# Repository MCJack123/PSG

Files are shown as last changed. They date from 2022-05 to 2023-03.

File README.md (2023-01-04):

# JackMacWindows's Programmable Sound Generator
This repo contains the source code for my programmable sound generation board. [Read the article for more info.](https://mcjack123.github.io/PSG/)

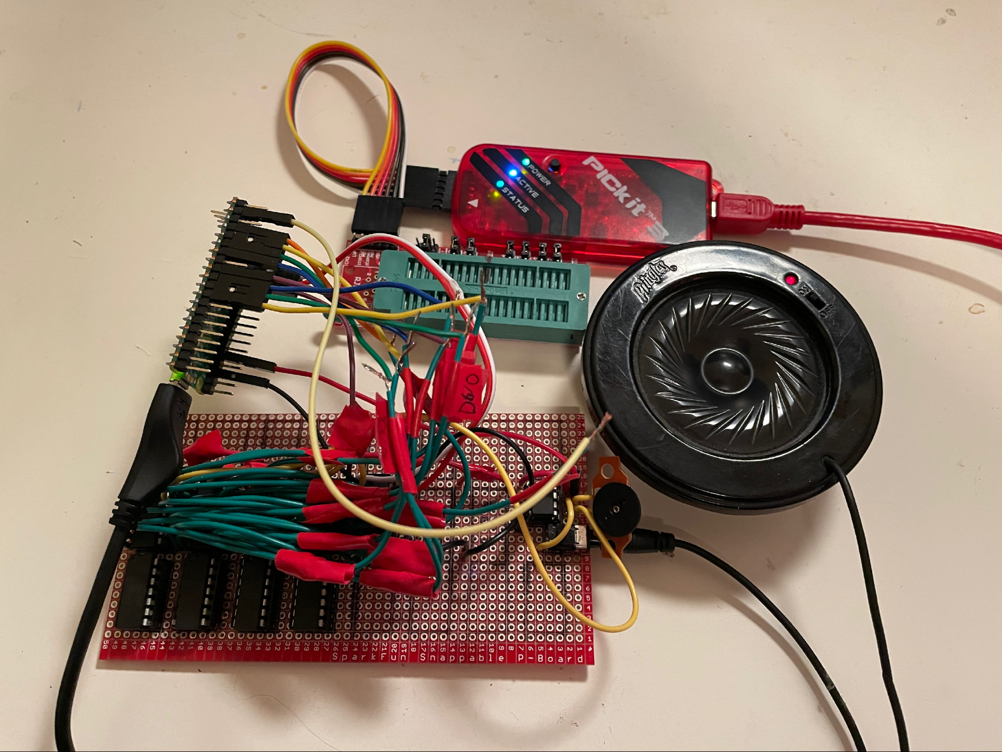
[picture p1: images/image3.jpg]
PSG image

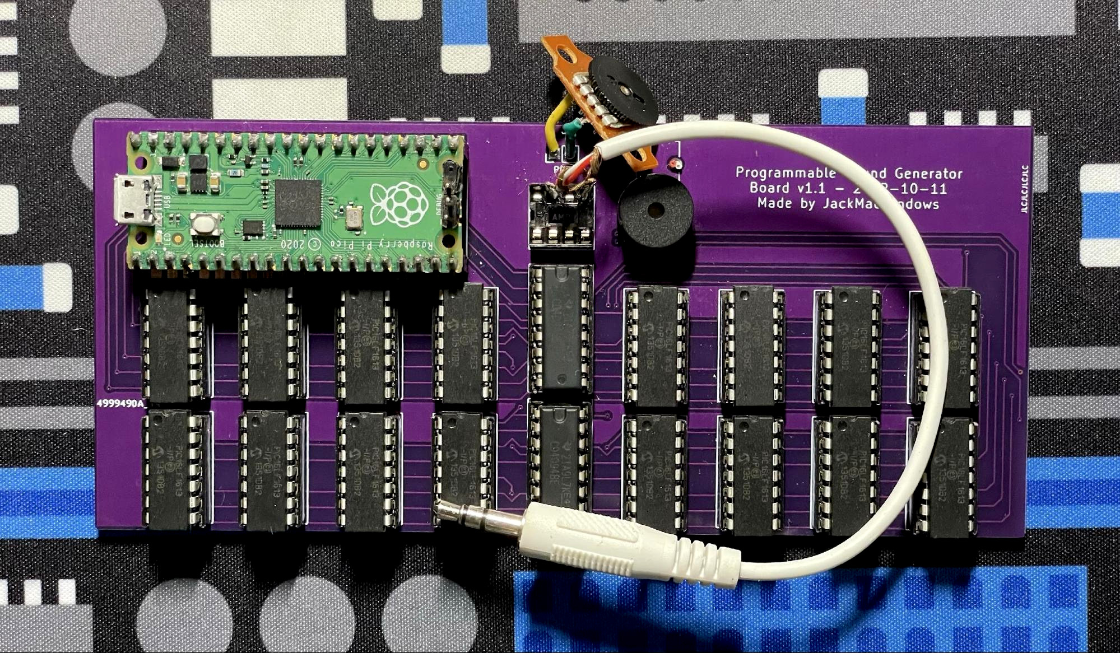
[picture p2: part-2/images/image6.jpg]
PSG image 2


## Contents
* `PSG-PCB` is a KiCad PCB layout for the complete 16-channel board.
* `PSG.X` contains an MPLAB X project with the wave generator code for the microcontrollers.
* `pico-sound-driver` contains a Raspberry Pi Pico project for managing the MCUs with a USB MIDI interface.
* `sound-midi.cpp` is a CraftOS-PC plugin for connecting to the board using the `sound` plugin interface.
* `programmer.cpp` is a program to quickly flash UF2, HEX, or BIN (concatenated HEX + UF2) firmware files to the PIC chips and the Pico. The current production firmware is available in `firmware.bin`.
* [`instrument-designer.html`](https://mcjack123.github.io/PSG/instrument-designer.html) is a small HTML+JS app to quickly design and upload instrument patches to the board.

## Documentation

### Mono/Poly Mode
The board has two different modes available. These modes are controlled by the standard CCs 126 and 127.

In mono mode, each channel can play one frequency and has its own global program and volume settings. This has a 1:1 correlation with each chip - one MIDI channel controls its corresponding chip number. Instruments are not available in this mode - instead, the program number (from 0-7, looping after) controls the wave type directly, as if the instrument bank was just initialized.

In poly mode, chips are allocated as needed for each note to play. Programs are assigned to each channel, and instruments are available.

### Direct Parameter Control
To support being able to directly control the parameters of each chip, some CCs are added to control the frequency instead of requiring note+pitch bend messages. See below for more information on those. In addition, when in mono mode, the standard volume and program change settings will directly affect the chips.

### Stereo Support
Firmware version 1.2.0 adds support for stereo output on board revisions that support it (v1.2.0 or later). There are three modes available: center (default), split stereo, and full stereo. In split stereo mode, all 16 voices are available, but the first eight will go straight to the left side, and the second eight will go to the right side. This is most effective when in mono note mode. Full stereo reduces the number of available voices to 8, but plays notes with chips on both sides, making them audible on both sides, as well as enabling panning using the CC & envelope.

### Instruments
Instruments allow attaching envelopes to waves for continuous changes to certain parameters. Four envelopes are available for controlling volume, panning, frequency adjustment, and duty cycle (square waves only). Instruments replace basic wave type controls in poly mode, and all 128 programs in MIDI have instruments attached.

Envelopes are based on the XM module format's envelope design. Each envelope has a maximum of 12 points available, each storing 16-bit pairs of X/Y coordinates. The X axis indicates the time of the point, in hundredths of a second. The Y axis stores the MIDI value of the control for everything except frequency. The frequency envelope's Y axis is the number of 16ths of a semitone to offset the note by, with a value of `0x8000` being centered at ±0.

Each envelope also has the ability to loop between certain points. There are three modes: one shot, which plays the envelope straight and ends at the last point, regardless of note off; sustain, which holds the envelope position at the *sustain point* until the note is released; and loop, which jumps the position in the envelope back to the loop start point when it reaches the loop end point. (Sustain mode functions like loop mode as if the start and end point were the same.)

By default, the instrument list is filled with basic instruments with no envelopes. The wave types cycle in the same order as mono mode, but program numbers divisible by 8 hold square waves with increasing default duty levels (for example, program 8 is a 1/16 duty square wave, program 32 is a 1/4 duty square wave, etc.). Program 0 is also set to a 1/2 duty square wave, as a duty of 0 is invalid.

### CC List
This table lists all available CCs.

| CC  | Description |
|-----|---|
| 1 | Square wave duty cycle |
| 7 | Volume |
| 10  | Pan (full stereo mode only) |
| 24  | Frequency (MSB) |
| 56  | Frequency (LSB) |
| 86  | Stereo mode: `0x40` -> stereo enable bit, `0x20` -> dual channel bit |
| 123 | All notes off |
| 126 | Mono mode |
| 127 | Poly mode |

### Wave Types
| Code | Wave |
|---|---|
| 0 | None, or square |
| 1 | Sine |
| 2 | Triangle |
| 3 | Saw (ascending) |
| 4 | Saw (descending) |
| 5 | Square |
| 6 | Noise  |
| 7 | Undefined |

### SysEx List
PSG accepts SysEx commands with vendor ID `00 46 71`. Commands are followed by two bytes for the command number in little endian.

| Command | Data | Description |
|---|---|---|
| `00 00` | HEX file | Flash PIC firmware to all attached chips |
| `01 F7` | None | Enter UF2 bootloader mode |
| `02 00` | Patch number, instrument data | Upload instrument data to program slot |

#### Instrument data
Instruments are stored in a 212-byte binary block encoded with Base64. Point coordinates are in little endian.

| Offset | Size | Description |
|---|---|---|
| `0x00` | 2 | X coordinate of first point in volume envelope |
| `0x02` | 2 | Y coordinate of first point in volume envelope |
| `0x04` | 2/2  | X/Y coordinates of second point in volume envelope |
| `0x08` | 40 | ...10 more points |
| `0x30` | 1 | Number of points in volume envelope |
| `0x31` | 1 | Sustain point number in volume envelope (`0xFF` = no sustain) |
| `0x32` | 1 | Loop start point number in volume envelope (`0xFF` = no loop) |
| `0x33` | 1 | Loop end point number in volume envelope (`0xFF` = no loop) |
| `0x34` | 52 | Pan envelope |
| `0x68` | 52 | Frequency envelope |
| `0x9C` | 52 | Duty envelope |
| `0xD0` | 1 | Wave type |
| `0xD1` | 3 | Reserved, set to 0 |

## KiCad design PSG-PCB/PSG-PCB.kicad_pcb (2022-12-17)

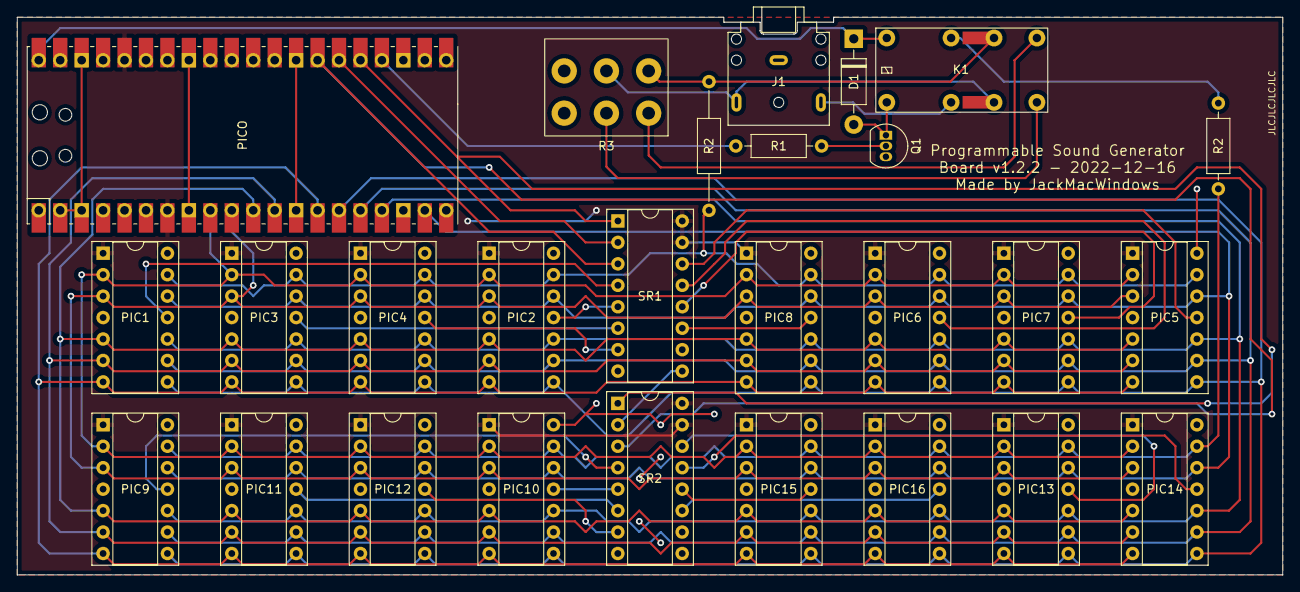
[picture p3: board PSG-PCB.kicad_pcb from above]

Board: 2 copper layers, 149.9 x 66.0 mm, 9 parts (0 on the bottom side), 12 nets.

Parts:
D1: D_DO-41_SOD81_P10.16mm_Horizontal
J1: Jack_3.5mm_CUI_SJ1-3523N_Horizontal
K1: Relay_DPDT_CIT_J104D
PICO: RPi_Pico_SMD_TH
Q1: TO-92_Inline
R1: 1K; R_Axial_DIN0207_L6.3mm_D2.5mm_P10.16mm_Horizontal
R2: 150K; R_Axial_DIN0207_L6.3mm_D2.5mm_P15.24mm_Horizontal
R2#2: 150K; R_Axial_DIN0207_L6.3mm_D2.5mm_P10.16mm_Horizontal
R3: Potentiometer_Bourns_PDB182-K_Horizontal

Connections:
5V: D1.1, K1.1, PICO.40
Audio_In_Amp: K1.5, R2.2, R3.3
Audio_In_R_Amp: K1.7, R3.6
Audio_In_R_Res: K1.3, R2#2.2
Audio_Out: J1.T, K1.6, R3.2
Audio_Out_R: K1.8, R3.5
Audio_Pin_R: J1.R, K1.4
Ground: J1.S, PICO.1, PICO.2, PICO.3, PICO.4, PICO.5, PICO.6, PICO.8, PICO.13, PICO.18, PICO.23, PICO.28, PICO.33, PICO.38, Q1.3, R3.1, R3.4
Relay_Sink: D1.2, K1.2, Q1.1
Stereo: PICO.24, R1.1
T_Base: Q1.2, R1.2
VDD: PICO.7, PICO.36

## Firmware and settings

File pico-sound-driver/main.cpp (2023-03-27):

/*
 * pico-sound-driver/main.cpp
 * PSG
 *
 * This file contains the firmware for the Raspberry Pi Pico. It handles parsing
 * MIDI events and converting them into commands for each channel, as well as
 * other miscellaneous functionality, such as fade out and PIC firmware updates.
 *
 * This code is licensed under the GPLv2 license.
 * Copyright (c) 2022-2023 JackMacWindows.
 */

#include <hardware/flash.h>
#include <hardware/gpio.h>
#include <hardware/timer.h>
#include <hardware/watchdog.h>
#include <pico/mutex.h>
#include <pico/multicore.h>
#include <pico/bootrom.h>
#include <tusb.h>
#include <math.h>
#include <stdio.h>

#define BOARD_VERSION_MAJOR 0
#define BOARD_VERSION_MINOR 1

#define MAX_CHANNELS 16
#define NUM_CHANNELS (dualChannel ? MAX_CHANNELS / 2 : MAX_CHANNELS)
#ifndef M_PI
#define M_PI 3.14159265358979323846
#endif

#define gpio_out(pin) gpio_init(pin); gpio_set_dir(pin, true)
#define gpio_in(pin) gpio_init(pin); gpio_set_dir(pin, false)
#define COMMAND_WAVE_TYPE 0x00
#define COMMAND_VOLUME    0x40
#define COMMAND_FREQUENCY 0x80
#define COMMAND_CLOCK     0xC0

#define PIN_STROBE 19
#define PIN_DATA   20
#define PIN_CLOCK  21

#define sleep_us_sr(n) sleep_us((n))
#define sleep_us_pic(n) sleep_us((n))

// !! CLOCK MULTIPLIER CONSTANT !!
// UPDATE THIS IF MODIFYING THE RUN LENGTH OF THE LOOP CODE
#define CLOCKS_PER_LOOP 70

enum class WaveType {
    None,
    Sine,
    Triangle,
    Sawtooth,
    RSawtooth,
    Square,
    Noise,
    Custom,
    PitchedNoise
};

enum class InterpolationMode {
    None,
    Linear
};

struct Point {
    uint16_t x, y;
};

struct Envelope {
    Point points[12];
    uint8_t npoints = 0;
    uint8_t sustain = 0xFF;
    uint8_t loopStart = 0xFF;
    uint8_t loopEnd = 0xFF;
};

struct Instrument {
    Envelope volume;
    Envelope pan;
    Envelope frequency;
    Envelope duty;
    uint8_t waveTypes[4] = {0, 0, 0, 0};
};

struct ChannelInfo {
    // current status fields
    double position = 0.0;
    WaveType wavetype = WaveType::None;
    double duty = 0.5;
    unsigned int frequency = 0;
    double amplitude = 1.0;
    float pan = 0.0;
    // fade fields
    double fadeInit = 0.0;
    int64_t fadeStart = 0;
    int64_t fadeLength = 0;
    int fadeDirection = -1;
    // sound 2.0 (probably irrelevant here)
    double customWave[512];
    int customWaveSize;
    InterpolationMode interpolation;
    bool isLowFreq = false;
    uint8_t note = 0;
    // instrument fields
    Instrument * inst = NULL;
    uint16_t ticks[4] = {0, 0, 0, 0};
    uint8_t points[4] = {0, 0, 0, 0};
    uint8_t typeIndex = 0;
    bool release = false;
};

struct MidiPacket {
    uint8_t usbcode;
    uint8_t command;
    uint8_t param1;
    uint8_t param2;
};

extern char usb_serial[];
ChannelInfo channels[MAX_CHANNELS];
uint8_t typeconv[9] = {0, 5, 4, 2, 3, 1, 6, 0, 6};
const double freqMultiplier = (65536.0 * CLOCKS_PER_LOOP) / 8000000.0;
uint8_t midiChannels[16][128];
int midiPrograms[16] = {0};
uint8_t midiDuty[16] = {128};
uint8_t midiUsedChannels[MAX_CHANNELS] = {0xFF};
bool midiMode = true;
uint8_t command_queue[MAX_CHANNELS][4][2];
bool command_updates[4] = {false};
mutex_t command_queue_lock;
bool changed = false;
uint8_t freq_lsb[MAX_CHANNELS] = {0};
char hex_storage[0x4000];
uint16_t hex_storage_size = 0;
uint8_t inSysEx = 0;
uint16_t sysExSize;
uint8_t version_major, version_minor;
bool stereo = false, dualChannel = false;
Instrument patches[128];

/*
 * Base64 encoding/decoding (RFC1341)
 * Copyright (c) 2005-2011, Jouni Malinen <j@w1.fi>
 *
 * This software may be distributed under the terms of the BSD license.
 * See README for more details.
 */

static const uint8_t base64_table[65] =
	"ABCDEFGHIJKLMNOPQRSTUVWXYZabcdefghijklmnopqrstuvwxyz0123456789+/";

/**
 * base64_decode - Base64 decode
 * @src: Data to be decoded
 * @len: Length of the data to be decoded
 * @out: Pointer to output variable
 * @out_len: Length of output buffer
 * Returns: 0 on success, non-0 on error
 */
int base64_decode(const uint8_t *src, size_t len, uint8_t *out, size_t out_len) {
    static uint8_t dtable[256];
    static uint8_t dtable_done = 0;
	uint8_t *pos, block[4], tmp;
	size_t i, count, olen;
	int pad = 0;
    if (!dtable_done) {
        for (i = 0; i < 256; i++) dtable[i] = 0x80;
        for (i = 0; i < sizeof(base64_table) - 1; i++) dtable[base64_table[i]] = (uint8_t)i;
        dtable['='] = 0;
        dtable_done = 1;
    }
	count = 0;
	for (i = 0; i < len; i++) if (dtable[src[i]] != 0x80) count++;
	if (count == 0 || count % 4) return 1;
	olen = count / 4 * 3;
    if (out_len < olen) return 2;
	pos = out;
	count = 0;
	for (i = 0; i < len; i++) {
		tmp = dtable[src[i]];
		if (tmp == 0x80) continue;
		if (src[i] == '=') pad++;
		block[count] = tmp;
		count++;
		if (count == 4) {
			*pos++ = (block[0] << 2) | (block[1] >> 4);
			if (pad != 2) *pos++ = (block[1] << 4) | (block[2] >> 2);
			if (pad == 0) *pos++ = (block[2] << 6) | block[3];
			count = 0;
		}
	}
	return 0;
}

template<typename T> static T min(T a, T b) {return a < b ? a : b;}
template<typename T> static T max(T a, T b) {return a > b ? a : b;}

void writeWaveType(uint8_t c, WaveType type, uint8_t duty = 128) {
    command_queue[c][0][0] = COMMAND_WAVE_TYPE | typeconv[(int)type];
    if (type == WaveType::Square) command_queue[c][0][1] = duty;
    if (dualChannel) {
        command_queue[c+8][0][0] = COMMAND_WAVE_TYPE | typeconv[(int)type];
        if (type == WaveType::Square) command_queue[c+8][0][1] = duty;
    }
    command_updates[0] = true;
    changed = true;
}

void writeFrequency(uint8_t c, uint16_t freq) {
    freq = (uint16_t)floor(freq * freqMultiplier + 0.5);
    command_queue[c][1][0] = COMMAND_FREQUENCY | ((freq >> 8) & 0x3F);
    command_queue[c][1][1] = freq & 0xFF;
    if (dualChannel) {
        command_queue[c+8][1][0] = COMMAND_FREQUENCY | ((freq >> 8) & 0x3F);
        command_queue[c+8][1][1] = freq & 0xFF;
    }
    command_updates[1] = true;
    changed = true;
}

void writeVolume(uint8_t c, uint8_t vol) {
    if (dualChannel) {
        command_queue[c][2][0] = COMMAND_VOLUME | (uint8_t)floor(13.0 * log(vol * min(channels[c].pan + 1.0f, 1.0f) + 1) + 0.5);
        command_queue[c+8][2][0] = COMMAND_VOLUME | (uint8_t)floor(13.0 * log(vol * min(1.0f - channels[c].pan, 1.0f) + 1) + 0.5);
    } else {
        command_queue[c][2][0] = COMMAND_VOLUME | (uint8_t)floor(13.0 * log(vol + 1) + 0.5);
    }
    command_updates[2] = true;
    changed = true;
}

void write_data(uint8_t c, uint8_t data) {
    gpio_put(6, data & 0x80);
    gpio_put(7, data & 0x40);
    gpio_put(8, data & 0x20);
    gpio_put(9, data & 0x10);
    gpio_put(10, data & 0x08);
    gpio_put(11, data & 0x04);
    gpio_put(12, data & 0x02);
    gpio_put(13, data & 0x01);
    sleep_us_pic(channels[c].isLowFreq ? 16 : 1);
    gpio_put(14, true);
    sleep_us_pic(channels[c].isLowFreq ? 16 : 1);
    gpio_put(14, false);
    sleep_us_pic(channels[c].isLowFreq ? 48 : 3);
}

static int htob(const char **str, const char *end) {
    int n = 0;
    if (*str >= end) return -1;
    else if (**str >= '0' && **str <= '9') n += *(*str)++ - '0';
    else if (**str >= 'A' && **str <= 'F') n += *(*str)++ - 'A' + 10;
    else if (**str >= 'a' && **str <= 'f') n += *(*str)++ - 'a' + 10;
    else return -1;
    n <<= 4;
    if (*str >= end) return -1;
    else if (**str >= '0' && **str <= '9') n += *(*str)++ - '0';
    else if (**str >= 'A' && **str <= 'F') n += *(*str)++ - 'A' + 10;
    else if (**str >= 'a' && **str <= 'f') n += *(*str)++ - 'a' + 10;
    else return -1;
    return n;
}

int loadhex(const char *data, size_t size) {
    uint16_t program[0x800];
    struct {uint16_t start, end;} program_extents[16];
    uint8_t max_extent = 0;
    const char *end = data + size;
    uint16_t addr_hi = 0;
    memset(program, 0, 0x800);
    gpio_put(PICO_DEFAULT_LED_PIN, false);
    while (data < end && *data) {
        if (*data++ != ':') continue;
        uint8_t bc = htob(&data, end);
        if (bc == -1) return -3;
        bc >>= 1;
        uint16_t addr_h = htob(&data, end);
        if (addr_h == -1) return -4;
        uint16_t addr = htob(&data, end);
        if (addr == -1) return -5;
        addr |= addr_h << 8;
        addr >>= 1;
        uint8_t rec = htob(&data, end);
        if (rec == -1) return -6;
        switch (rec) {
            case 0: {
                for (int i = 0; i < bc; i++) {
                    if (addr_hi == 0) {
                        int l = htob(&data, end);
                        if (l == -1) return -7;
                        int h = htob(&data, end);
                        if (h == -1) return -8;
                        if (addr + i < 0x800) program[addr + i] = h << 8 | l;
                    } else {htob(&data, end); htob(&data, end);}
                }
                bool found = false;
                for (int i = 0; i < max_extent; i++) {if (program_extents[i].end == addr) {program_extents[i].end += bc; found = true; break;}}
                if (!found && max_extent < 16) program_extents[max_extent++] = {addr, (uint16_t)(addr + bc)};
                break;
            }
            case 1: {
                // execute programming
                // collapse extents over the same rows
                bool loop;
                do {
                    loop = false;
                    for (int i = 0; i < max_extent; i++) {
                        for (int j = 0; j < max_extent; j++) {
                            if ((program_extents[i].end & 0x7F0) == (program_extents[j].start & 0x7F0)) {
                                program_extents[i].end = program_extents[j].end;
                                for (int k = j + 1; k < max_extent; k++) program_extents[k-1] = program_extents[k];
                                max_extent--;
                                loop = true;
                            } else if ((program_extents[j].end & 0x7F0) == (program_extents[i].start & 0x7F0)) {
                                program_extents[j].end = program_extents[i].end;
                                for (int k = i + 1; k < max_extent; k++) program_extents[k-1] = program_extents[k];
                                max_extent--;
                                loop = true;
                            }
                        }
                    }
                } while (loop);
                // flip all chips into bootloader mode
                gpio_put(PIN_DATA, true);
                sleep_us(1);
                gpio_put(PIN_CLOCK, true);
                sleep_us(1);
                gpio_put(PIN_CLOCK, false);
                sleep_us(1);
                gpio_put(PIN_DATA, false);
                sleep_us(1);
                for (int i = 0; i < NUM_CHANNELS; i++) {
                    gpio_put(PIN_STROBE, true);
                    sleep_us(1);
                    gpio_put(PIN_STROBE, false);
                    gpio_put(PIN_CLOCK, true);
                    sleep_us(1);
                    gpio_put(PIN_CLOCK, false);
                    sleep_us(1);
                }
                gpio_put(PIN_STROBE, true);
                sleep_us(1);
                gpio_put(PIN_STROBE, false);
                channels[0].isLowFreq = true; // run slower for safety
                write_data(0, 0xFF); // system command
                write_data(0, 0x01); // enter bootloader
                for (int i = 0; i < max_extent; i++) {
                    for (uint16_t addr = program_extents[i].start & 0x7F0; addr < program_extents[i].end; addr += 0x10) {
                        uint8_t len = min(program_extents[i].end - addr, 0x10);
                        if (addr < 0x200) continue; // don't overwrite bootloader
                        write_data(0, len << 1);
                        write_data(0, addr >> 7);
                        write_data(0, addr << 1);
                        write_data(0, 0); // write data
                        sleep_ms(5); // wait for erase
                        for (int j = addr; j < addr + len; j++) {
                            write_data(0, program[j] & 0xFF);
                            write_data(0, program[j] >> 8);
                        }
                        sleep_ms(5); // wait for write
                        write_data(0, 0); // checksum is ignored
                    }
                }
                // send end code
                write_data(0, 0);
                write_data(0, 0);
                write_data(0, 0);
                write_data(0, 1);
                write_data(0, 0xFF);
                // notify host
                MidiPacket p = {0x0F, 0xFF, 0, 0};
                tud_midi_packet_write((uint8_t*)&p);
                sleep_ms(5); // is this needed?
                // reset
                //(*((volatile uint32_t*)(PPB_BASE + 0x0ED0C))) = 0x5FA0004;
                // we should be done by now, but just in case:
                watchdog_enable(1, 1);
                while (true);
            }
            case 4: {
                int haddr_h = htob(&data, end);
                if (haddr_h == -1) return -9;
                int haddr = htob(&data, end);
                if (haddr == -1) return -10;
                addr_hi = (haddr_h << 8) | haddr;
                break;
            }
            default: return -11;
        }
        htob(&data, end); // checksum
    }
    return -12;
}
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
int main() {
    gpio_init(PICO_DEFAULT_LED_PIN); gpio_set_dir(PICO_DEFAULT_LED_PIN, true);
    gpio_in(0);
    gpio_in(1);
    gpio_in(2);
    gpio_in(3);
    gpio_in(4);
    gpio_in(5);
    gpio_out(6);
    gpio_out(7);
    gpio_out(8);
    gpio_out(9);
    gpio_out(10);
    gpio_out(11);
    gpio_out(12);
    gpio_out(13);
    gpio_out(14);
    gpio_out(PIN_STROBE);
    gpio_out(PIN_DATA);
    gpio_out(PIN_CLOCK);
    // Check board version number (0-1 = major revision, 2-5 = minor revision)
    // major mismatch = do not run, minor mismatch = disable features
    version_major = (gpio_get(0) ? 2 : 0) + (gpio_get(1) ? 1 : 0);
    if (version_major != BOARD_VERSION_MAJOR) {
        while (true) {
            gpio_put(PICO_DEFAULT_LED_PIN, true);
            sleep_ms(500);
            gpio_put(PICO_DEFAULT_LED_PIN, false);
            sleep_ms(500);
        }
    }
    version_minor = (gpio_get(2) ? 8 : 0) + (gpio_get(3) ? 4 : 0) + (gpio_get(4) ? 2 : 0) + (gpio_get(5) ? 1 : 0);
    gpio_put(PIN_DATA, false);
    sleep_us(1);
    for (int i = 0; i < 32; i++) {
        gpio_put(PIN_CLOCK, true);
        sleep_us(1);
        gpio_put(PIN_CLOCK, false);
        sleep_us(1);
    }
    gpio_put(PIN_STROBE, true);
    sleep_us(1);
    gpio_put(PIN_CLOCK, true);
    sleep_us(1);
    gpio_put(PIN_CLOCK, false);
    sleep_us(1);
    gpio_put(PIN_STROBE, false);
    sleep_us(1);
    mutex_init(&command_queue_lock);
    for (int i = 0; i < MAX_CHANNELS; i++) {
        command_queue[i][0][0] = 0xFF;
        command_queue[i][1][0] = 0xFF;
        command_queue[i][2][0] = 0xFF;
        command_queue[i][3][0] = 0xFF;
    }
    memset(midiChannels, 0xFF, 2048);
    memset(midiUsedChannels, 0xFF, MAX_CHANNELS);
    for (uint8_t i = 0; i < 128; i++) {
        patches[i] = {
            { // volume
                {{0, 127}, {0, 0}, {0, 0}, {0, 0}, {0, 0}, {0, 0}, {0, 0}, {0, 0}, {0, 0}, {0, 0}, {0, 0}, {0, 0}},
                0, 0xFF, 0xFF, 0xFF
            },
            { // pan
                {{0, 64}, {0, 0}, {0, 0}, {0, 0}, {0, 0}, {0, 0}, {0, 0}, {0, 0}, {0, 0}, {0, 0}, {0, 0}, {0, 0}},
                0, 0xFF, 0xFF, 0xFF
            },
            { // frequency
                {{0, 0x8000}, {0, 0}, {0, 0}, {0, 0}, {0, 0}, {0, 0}, {0, 0}, {0, 0}, {0, 0}, {0, 0}, {0, 0}, {0, 0}},
                0, 0xFF, 0xFF, 0xFF
            },
            { // duty
                {{0, i == 0 ? (uint16_t)64 : (uint16_t)i}, {0, 0}, {0, 0}, {0, 0}, {0, 0}, {0, 0}, {0, 0}, {0, 0}, {0, 0}, {0, 0}, {0, 0}, {0, 0}},
                (i == 0 || i % 8 == 5) ? (uint8_t)0 : (uint8_t)1, 0, 0xFF, 0xFF
            },
            {i % 8 == 0 ? (uint8_t)5 : (uint8_t)(i % 8), 0, 0, 0} // waveTypes
        };
    }
    uint64_t serial = 0;
    flash_get_unique_id((uint8_t*)&serial);
    sprintf(usb_serial, "%016lx", serial);
    usb_serial[16] = ':';
    tusb_init();
    multicore_launch_core1(core2);
    gpio_put(PICO_DEFAULT_LED_PIN, true);
    while (true) tud_task(); // tinyusb device task
}

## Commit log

2022-11-04 Version 1.x Initial Upload
    Documentation and a write-up to come soon.
    [PSG-PCB.kicad_pcb]
2022-11-27 Fixed a few things in the Pico code
    (Aftertouch, instrument 0, poly mode not working)
    [main.cpp]
2022-12-09 Added demos, MIDI plugin (oops), tiny fixes
    [main.cpp]
2022-12-17 Added license, removed old files, added version number
    [board.fzz]
2022-12-17 Redesigned board volume control, added version check
    [PSG-PCB.kicad_pcb]
